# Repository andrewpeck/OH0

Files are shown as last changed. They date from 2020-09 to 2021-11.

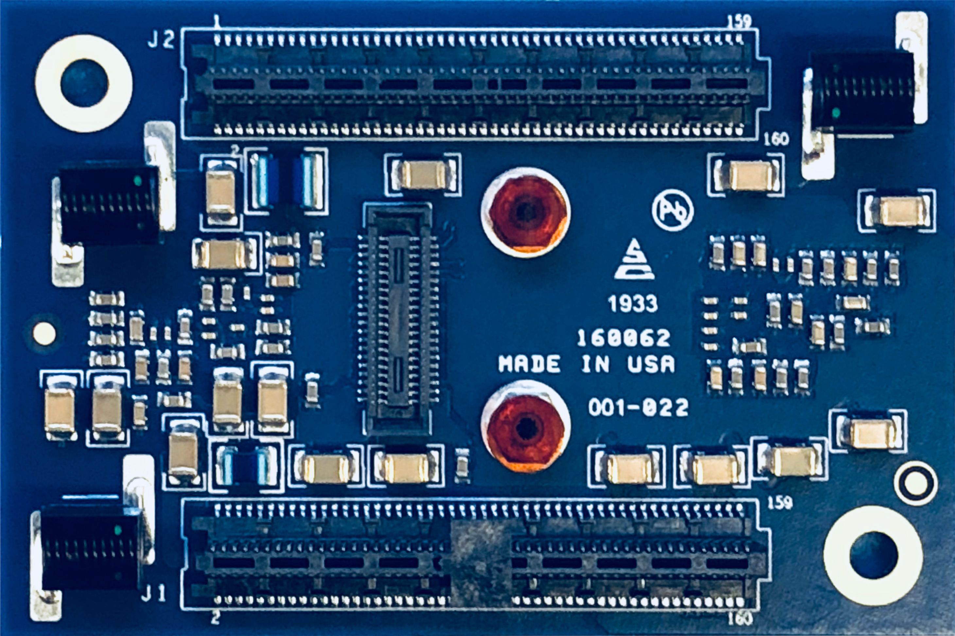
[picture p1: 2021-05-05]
Doc/ASIAGO_BOTTOM.jpeg

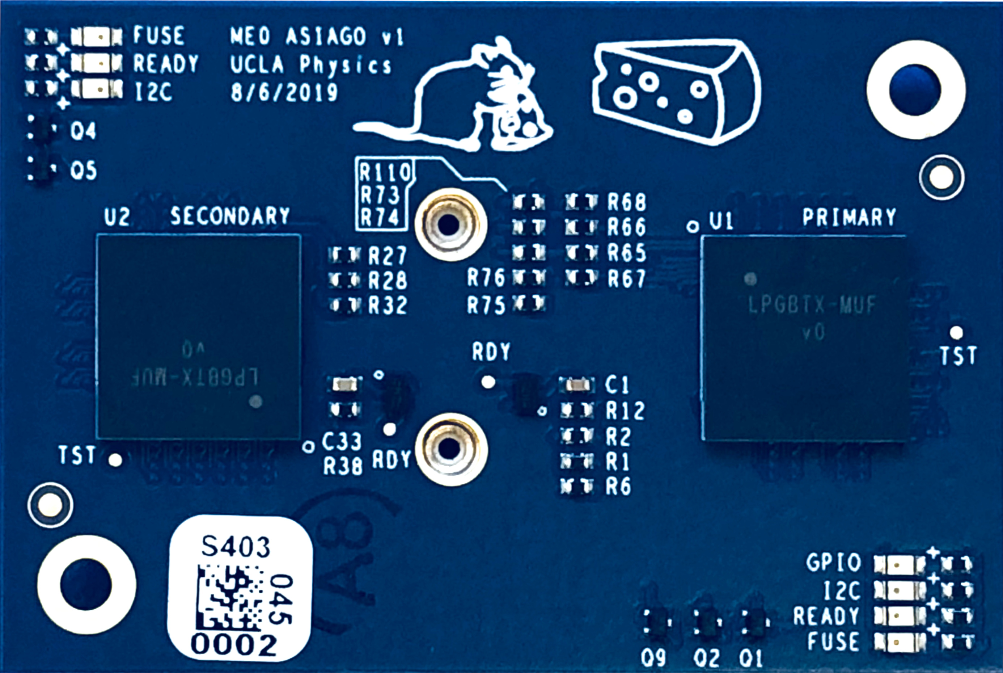
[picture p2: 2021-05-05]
Doc/ASIAGO_TOP.jpeg

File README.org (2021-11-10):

#+TITLE: ME0 ASIAGO

/ASIAGO: a strong-flavored cow's milk cheese originally made in northern Italy. In this case, ASIAGO is the ASIC and Gigabit Optics./

#+html: <p><img width="300" alt="ME0 ASIAGO Top" src="Doc/ASIAGO_TOP.jpeg" /> <img width="300" alt="ME0 ASIAGO Bottom" src="Doc/ASIAGO_BOTTOM.jpeg" /></p>

#+BEGIN_SRC
├── README.org
├── Footprints  ; Allegro Footprints
├── Doc         ; Images, etc.
├── Layout      ; Allegro Layout
├── Padstacks   ; Allegro Padstacks
├── Release     ; Released production files
└── Schematic   ; OrCAD Schematic + Library
#+END_SRC

- [[https://twiki.cern.ch/twiki/pub/CMS/ME0ASIAGO/me0_asiago_interfaces.pdf][ME0 ASIAGO Interfaces]]
- [[https://twiki.cern.ch/twiki/pub/CMS/ME0ASIAGO/ME0_OH_v2_Specification.pdf][ME0 ASIAGO Specifications]]
- [[https://twiki.cern.ch/twiki/bin/view/CMS/ME0ASIAGO][ME0 ASIAGO Twiki]]

* Datasheets
** LPGBT
- [[https://lpgbt.web.cern.ch/lpgbt/manual/][lpGBT Manual]]
- [[https://indico.cern.ch/event/697988/contributions/3075493/attachments/1720215/2776778/lpGBTtutorialTwepp20180921.pdf][lpGBT: A User's Perspective]]
- [[https://espace.cern.ch/GBT-Project/LpGBT/Specifications/LpGbtxSpecifications.pdf][lpGBT Specifications]]
- [[https://espace.cern.ch/GBT-Project/LpGBT/Presentations/Forms/AllItems.aspx][lpGBT Presentations]]
** VTRX+
- [[https://edms.cern.ch/ui/#!master/navigator/project?P:1930058715:1767090345:subDocs][VTRX+ EDMS]]
- [[https://edms.cern.ch/file/1719329/1/VTRxPlus_spec_v2.4.pdf][VTRx+ Specification]]
- [[https://edms.cern.ch/file/2149674/1/VTRxPlusApplicationNote.pdf][VTRx+ Application Note]]
- [[https://www.hirose.com/product/document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][DF40C(2.0)-40DS-0.4V(51)]]
** Other Components
All of these components are meant to be used in non-critical circuitry.
- [[http://rohmfs.rohm.com/en/products/databook/datasheet/discrete/transistor/mosfet/rum001l02t2cl-e.pdf][RUM001L02]]
- [[https://www.ti.com/lit/ds/symlink/sn74aup1g17.pdf][SN74AUP1G17]]
- [[http://suddendocs.samtec.com/catalog_english/st5.pdf][ST5-50-1.50-L-D-P]]
- [[https://www.puiaudio.com/media/SpecSheet/SMT-0340-T-R.pdf][SMT-0340-T-R]]
- [[https://www.diodes.com/assets/Datasheets/BAS521Q.pdf][BAS521Q-13]]
- [[https://optoelectronics.liteon.com/upload/download/DS22-2007-0094/LTST-C193KGKT-5A.PDF][LTST-C193KGKT-5A]] (Green)
- [[https://optoelectronics.liteon.com/upload/download/DS22-2005-077/LTST-C193KRKT-5A.PDF][LTST-C193KRKT-5A]] (Red)
* Misc
**  Design Files:
*** v2
|-----------------------+---------------------------------------------------------------------------------|
| File                  | Link                                                                            |
|-----------------------+---------------------------------------------------------------------------------|
| Schematic PDF         | https://twiki.cern.ch/twiki/pub/CMS/ME0ASIAGO/me0_asiago_schematic_20211110.pdf |
| Artwork PDF           | https://twiki.cern.ch/twiki/pub/CMS/ME0ASIAGO/me0_asiago_artwork_20211110.pdf   |
| Bill of Materials     | https://twiki.cern.ch/twiki/pub/CMS/ME0ASIAGO/me0_asiago_bom_20211110.xlsx      |
| Gerber / Drill / Pick | https://twiki.cern.ch/twiki/pub/CMS/ME0ASIAGO/me0_asiago_artwork_20211110.zip   |
| ODB++                 | https://twiki.cern.ch/twiki/pub/CMS/ME0ASIAGO/me0_asiago_odb_20211110.zip       |
| Orcad/Allegro Project | https://twiki.cern.ch/twiki/pub/CMS/ME0ASIAGO/me0_asiago_project_20211110.zip   |
| 3D Model (step)       | https://twiki.cern.ch/twiki/pub/CMS/ME0ASIAGO/me0_asiago_step_20211110.stp      |
| Stackup               | [[https://twiki.cern.ch/twiki/pub/CMS/ME0ASIAGO/ME0_ASIAGO_-_Rev2_%28Pactron%29--8_%28051421%29.xls][ME0_ASIAGO_Rev2_stackup.xls]]                                                     |
|-----------------------+---------------------------------------------------------------------------------|
*** v1
|-----------------------+---------------------------------------------------------------------------------|
| File                  | Link                                                                            |
|-----------------------+---------------------------------------------------------------------------------|
| Schematic PDF         | https://twiki.cern.ch/twiki/pub/CMS/ME0ASIAGO/me0_asiago_schematic_20190806.pdf |
| Artwork PDF           | https://twiki.cern.ch/twiki/pub/CMS/ME0ASIAGO/me0_asiago_artwork_20190806.pdf   |
| Bill of Materials     | https://twiki.cern.ch/twiki/pub/CMS/ME0ASIAGO/me0_asiago_bom_20190806.xlsx      |
| Gerber / Drill / Pick | https://twiki.cern.ch/twiki/pub/CMS/ME0ASIAGO/me0_asiago_artwork_20190806.zip   |
| ODB++                 | https://twiki.cern.ch/twiki/pub/CMS/ME0ASIAGO/me0_asiago_odb_20190806.zip       |
| Orcad/Allegro Project | https://twiki.cern.ch/twiki/pub/CMS/ME0ASIAGO/me0_asiago_project_20190806.zip   |
| Stackup               | https://twiki.cern.ch/twiki/pub/CMS/ME0ASIAGO/ch1447158_1.pdf                   |
|-----------------------+---------------------------------------------------------------------------------|
** Notes
VL+ Fiber Mapping: #7 = Master RX, # 5 = Master TX, # 6 = Slave RX

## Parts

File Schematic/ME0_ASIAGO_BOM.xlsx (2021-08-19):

Item Number | Quantity | Value | Description | Part Reference | Manufacturer | Manufacturer Part Number
1 | 14 | 4.7 uF | CAP CER 4.7UF 6.3V X5R 0402 | C1 C4 C5 C15 C16 C27 C28 C36 C37 C47 C48 C59 C60 C124 | Murata | GRM155R60J475ME87D
2 | 13 | 47 uF | CAP CER 47UF 10V X5R 0805 | C2 C14 C31 C32 C34 C46 C87 C97 C98 C118 C120 C122 C123 | Murata | GRM21BR61A476ME15L
3 | 23 | 0.47 uF | CAP CER 0.47UF 10V X5R 0402 | C6 C7 C8 C18 C19 C20 C21 C22 C23 C29 C38 C39 C40 C50 C51 C52 C53 C54 C55 C61 C117 C119 C121 | Samsung | CL05A474KP5NNNC
4 | 14 | 10 nF | CAP CER 10000PF 10V X7R 0201 | C10 C11 C12 C13 C24 C25 C30 C42 C43 C44 C45 C56 C57 C62 | Murata | GRM033R71A103KA01D
5 | 8 | Green | LED GREEN CLEAR CHIP SMD | D1 D4 D15 D16 D17 D18 D19 D20 | Lite-On Inc. | LTST-C193KGKT-5A
6 | 2 | Red | LED RED CLEAR CHIP SMD | D9 D10 | Lite-On Inc. | LTST-C193KRKT-5A
7 | 1 | BAS521Q-13 | Diode Standard 300 V 250mA (DC) Surface Mount SOD-523 | D22
8 | 2 | ST5-50-1.50-L-D-P | Samtec Razorbeam 0.5mm Strip Assembly | J1 J2 | Samtec | ST5-50-1.50-L-D-P
9 | 1 | DF40C(2.0)-40DS-0.4V(51) | CONN RCPT 40POS 0.4MM SMD GOLD | J3 | Hirose | DF40C(2.0)-40DS-0.4V(51)
10 | 1 | SMT-0340-T-R |  | LS1
11 | 1 | M2_MOUNT |  | M3
12 | 1 | M2_MOUNT |  | M4
13 | 1 | M1P6_CLEARANCE_HOLE |  | M5
14 | 1 | M1P6_CLEARANCE_HOLE |  | M6
15 | 4 | RUM001L02T2CL | MOSFET N-CH 20V 0.1A VMT3 | Q2 Q5 Q9 Q10 | ROHM | RUM001L02T2CL
16 | 10 | 4.7k | RES SMD 4.7K OHM 5% 1/10W 0402 | R1 R2 R27 R28 R73 R74 R75 R76 R86 R122 | Panasonic | ERJ-2GEJ472X
17 | 5 | 270R | RES SMD 270 OHM 5% 1/10W 0402 | R3 R29 R83 R84 R109 | Panasonic | ERJ-2GEJ271X
18 | 3 | 1k | RES SMD 1K OHM 0.1% 1/16W 0402 | R66 R111 R112 | Panasonic | ERA-2AEB102X
19 | 1 | 500R |  | R68 | Panasonic
20 | 1 | 4.7k |  | R110
21 | 3 | 0R | RES SMD 0 OHM 1% 1/10W 0402 | R113 R114 R130 | Panasonic | RMCF0402ZT0R00
22 | 1 | 1M |  | R116
23 | 2 | 470k |  | R117 R137
24 | 7 | 1k |  | R118 R131 R132 R133 R134 R135 R138
25 | 2 | 999G | Do Not Stuff | R119 R129 |  | Do Not Place
26 | 2 | 1R |  | R120 R121 |  | RC0402FR-071RL
27 | 1 | 33R |  | R136
28 | 1 | NTCG103UH103JT1 |  | RT1 |  | NTCG103UH103JT1
29 | 3 | TPPAD | Do Not Stuff | TP7 TP20 TP21 | Do Not Stuff | Do Not Stuff
30 | 2 | LpGBT | CERN LpGBT | U1 U2 | CERN | LpGBT
31 | 1 | SN74AUP1G17DRY | IC BUFFER NON-INVERT 3.6V 6SON | U3 | Texas Instruments | SN74AUP1G17DRYR

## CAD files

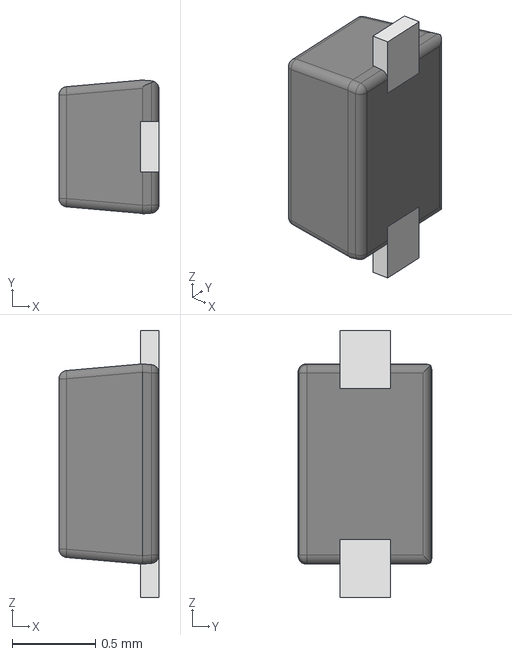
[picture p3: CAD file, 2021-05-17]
Footprints/STEP/SOD523.stp
0.6 x 0.803 x 1.60 mm
SOD523 LF
SOD523 compound

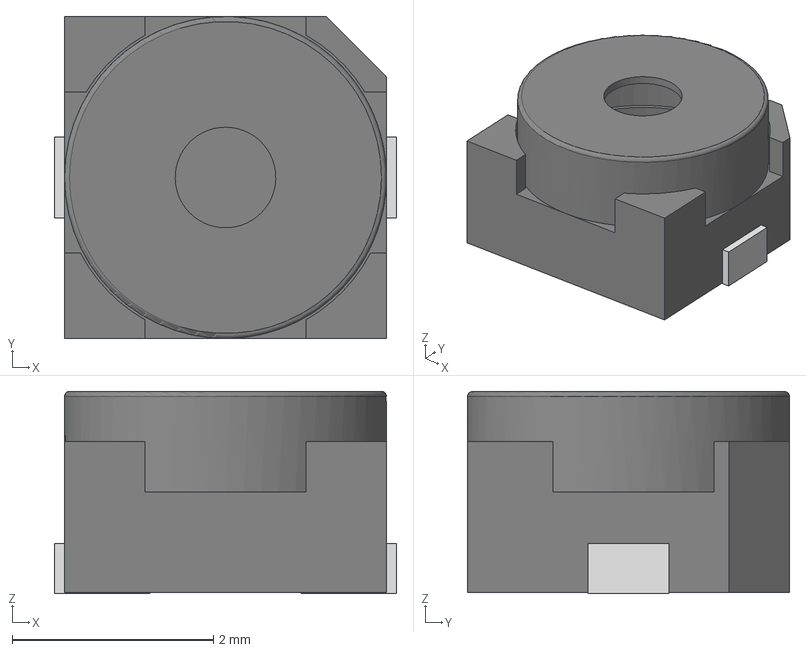
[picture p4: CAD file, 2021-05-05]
Footprints/STEP/SMT-0340-T-R.stp
3.40 x 3.20 x 2.01 mm
Lower Housing
Upper Housing

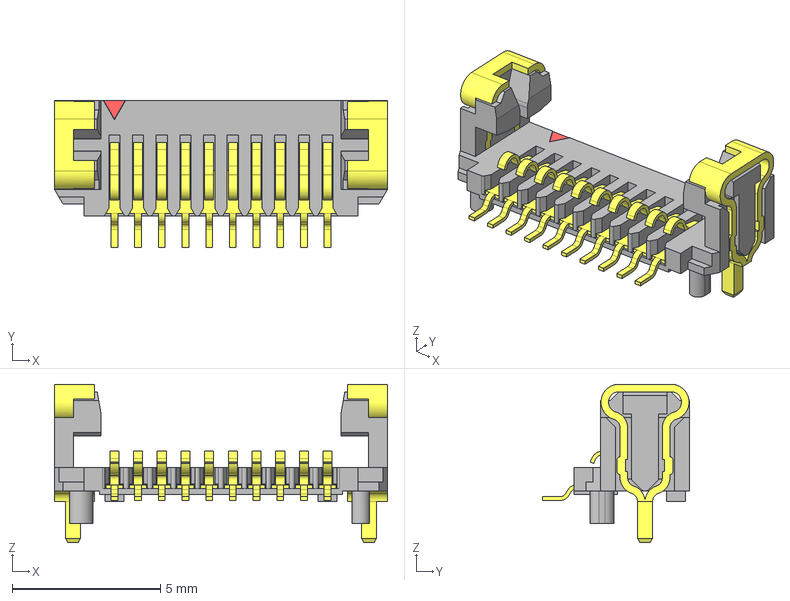
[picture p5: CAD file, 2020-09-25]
Footprints/STEP/UCC8-010-1-H-S-1-A.stp
11.2 x 4.96 x 5.35 mm
_UCC8-010-1-H-S-1-A_t
_UCC8-010-1-H-S-1-A_wt x 2
_UCC8-010-1-H-S-1-A_p
_UCC8-010-1-H-S-1-A_tr

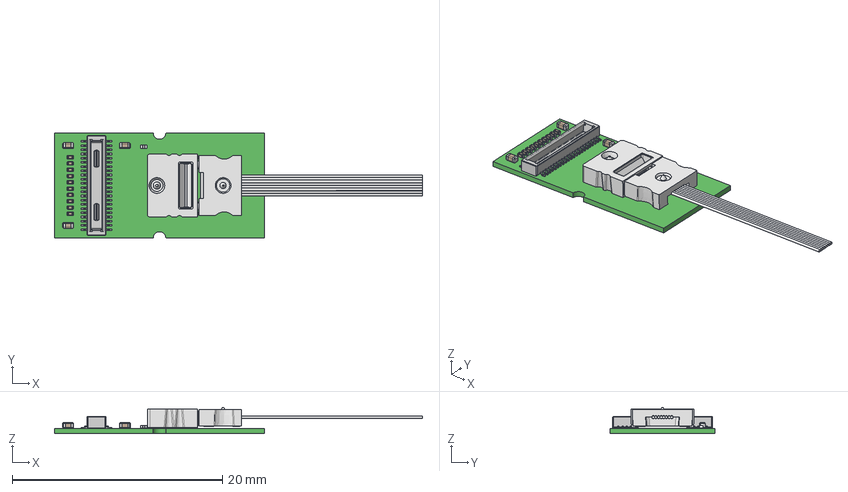
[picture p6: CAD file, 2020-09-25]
Footprints/STEP/CERN_VTRxPlus_V7_with_pigtail.stp
35.0 x 10.0 x 2.51 mm
Board
CAPC0603X33N x 10
RESC0603X28N
DF40C-40DP
PHILIPS_ULMPIN-14-TT-N0101U
PHILIPS_ULM850-14-TT-N0104U
CAPC1005X55N x 3
CERN_GBTIA
CERN_LDQ10v2
OT-006_f
OT-007_f
ribbon

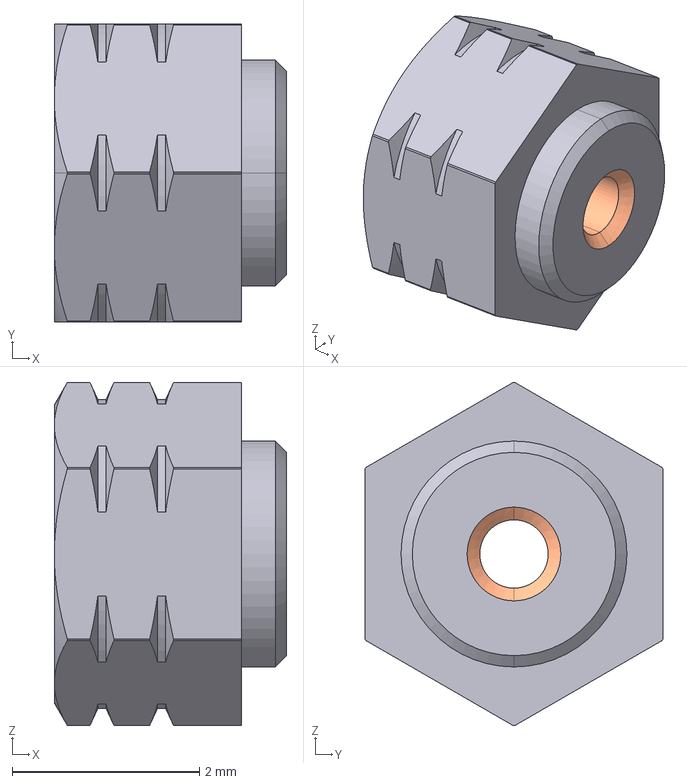
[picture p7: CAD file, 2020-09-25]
Footprints/STEP/SMTSO-M1-2ET-PennEngineering-05-24-2018.stp
2.48 x 3.18 x 3.66 mm

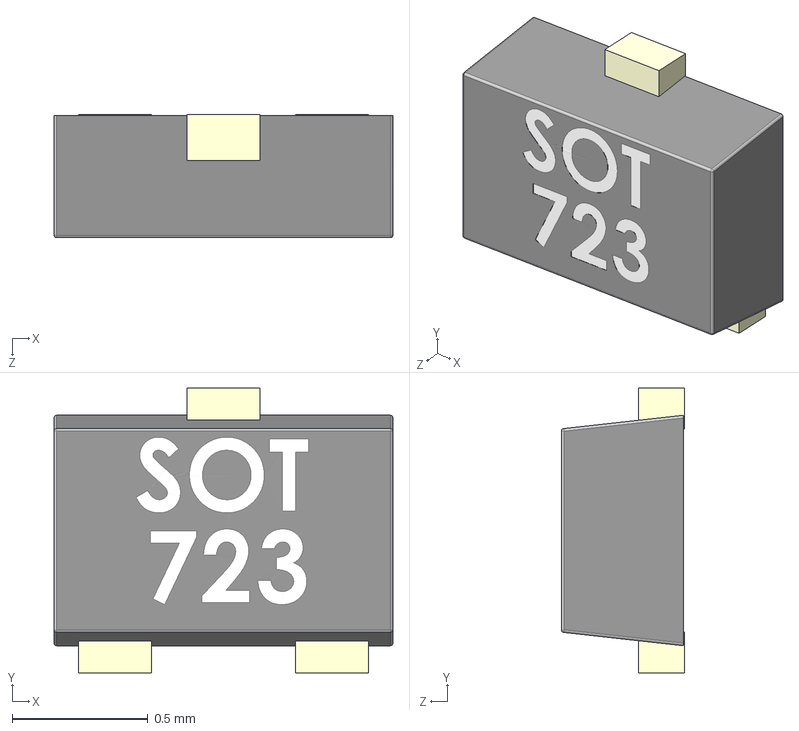
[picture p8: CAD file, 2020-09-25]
Footprints/STEP/User Library-SOT-723.step
1.25 x 1.05 x 0.455 mm

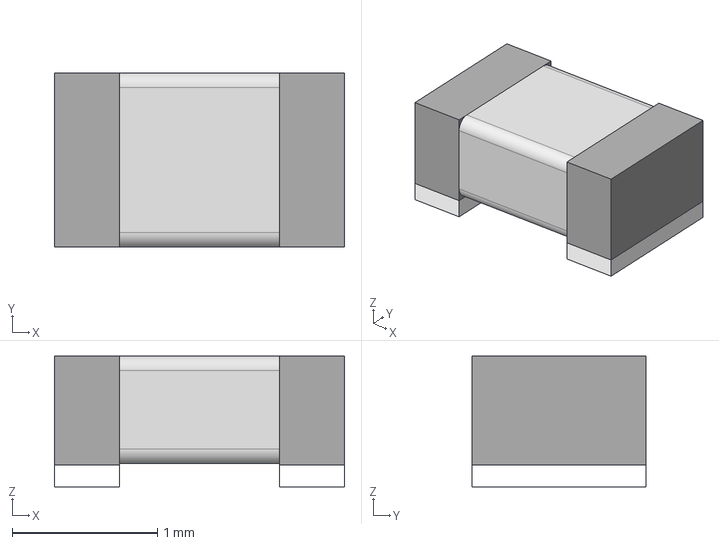
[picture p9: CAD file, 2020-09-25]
Footprints/STEP/LQW21HN.stp
2.00 x 1.20 x 0.9 mm

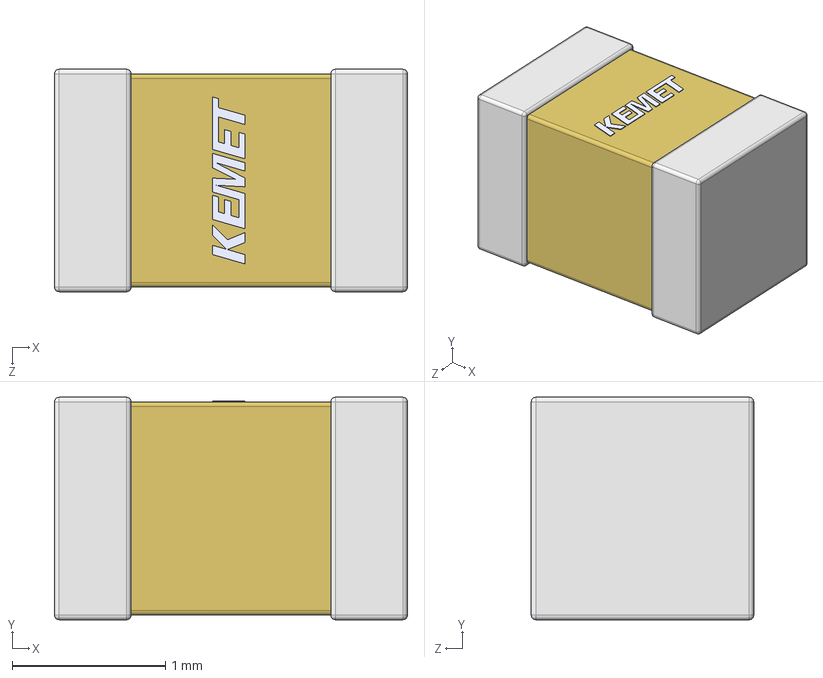
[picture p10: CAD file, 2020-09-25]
Footprints/STEP/C0805.step
2.30 x 1.45 x 1.45 mm

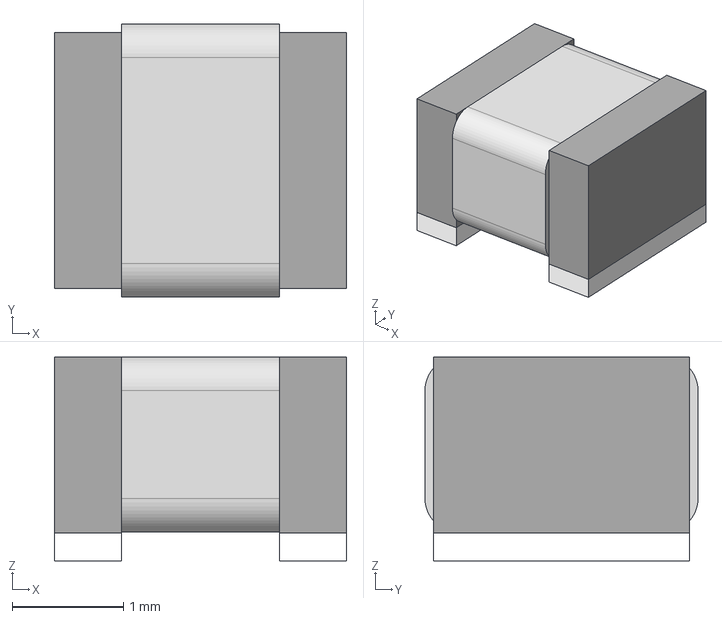
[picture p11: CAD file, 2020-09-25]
Footprints/STEP/LQW2UAN.stp
2.62 x 2.45 x 1.83 mm

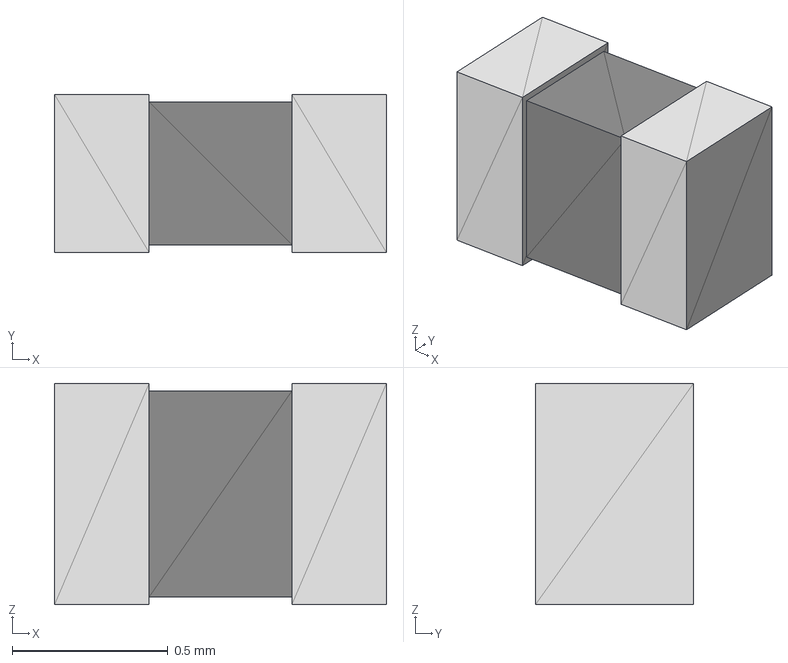
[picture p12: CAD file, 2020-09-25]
Footprints/STEP/RES_0402.stp
1.07 x 0.508 x 0.711 mm

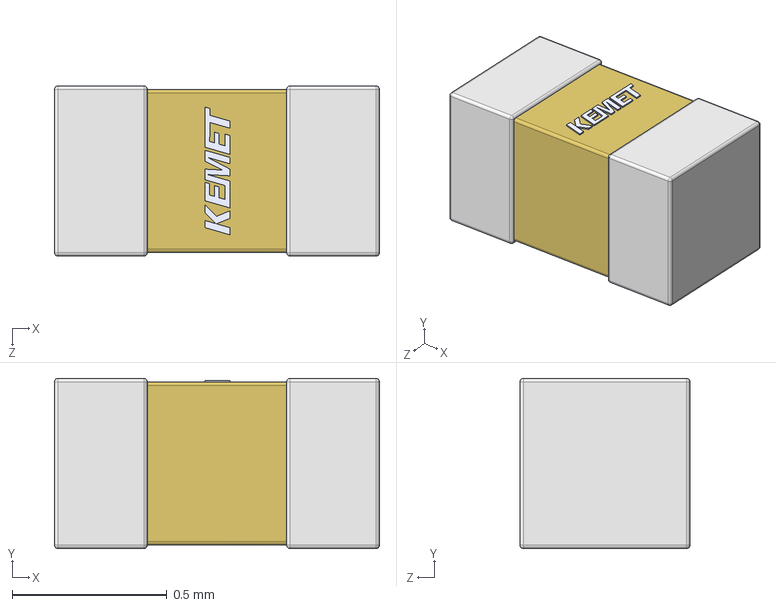
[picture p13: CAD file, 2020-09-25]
Footprints/STEP/C0402.step
1.05 x 0.55 x 0.55 mm

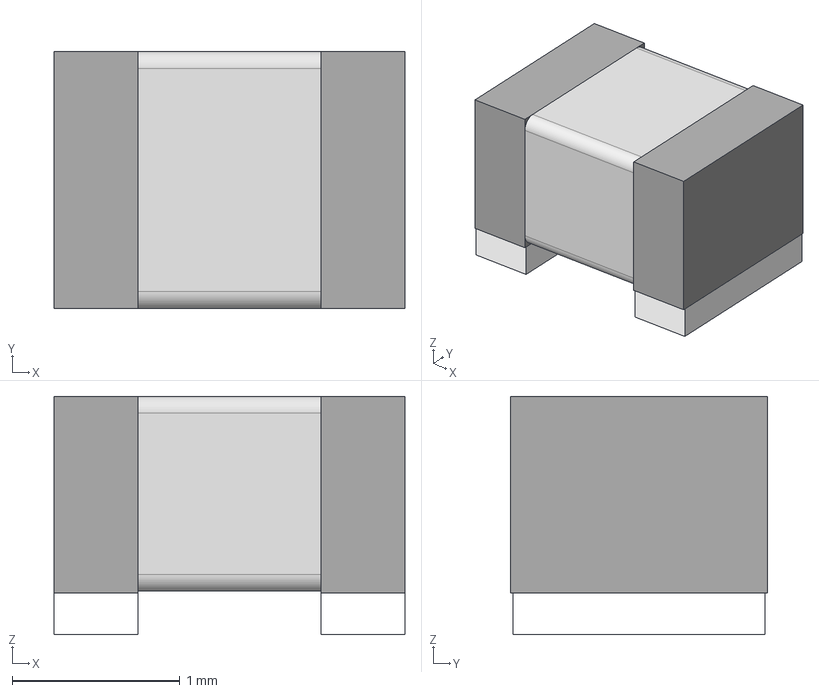
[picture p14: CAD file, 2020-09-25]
Footprints/STEP/LQW2BAN.stp
2.09 x 1.53 x 1.42 mm

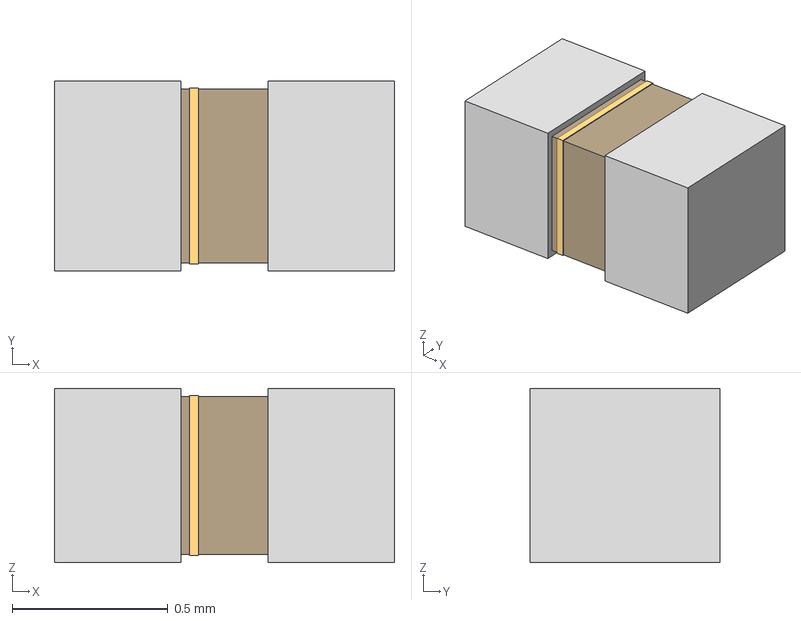
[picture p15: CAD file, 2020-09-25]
Footprints/STEP/CAP_0402C.step
1.09 x 0.61 x 0.559 mm

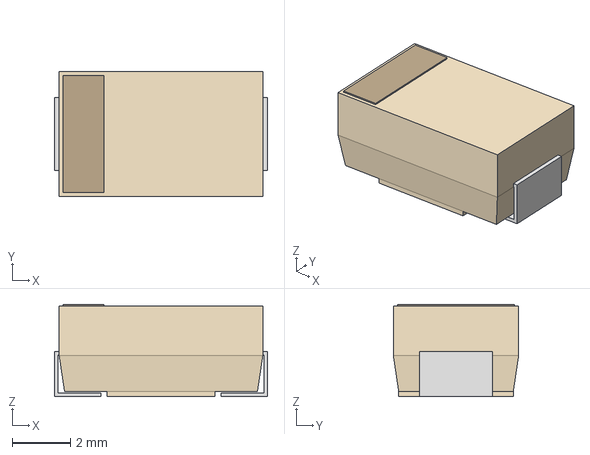
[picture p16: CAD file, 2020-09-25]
Footprints/STEP/PCAP7343-31_Kemet-M.step
7.29 x 4.29 x 3.15 mm

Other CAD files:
Footprints/STEP/LQW31HN.stp
Footprints/STEP/LQW2BHN.stp
Footprints/STEP/CAP_0402C-L.step
Footprints/STEP/C1206.step
Footprints/1812sms-r15_l_.psm
Footprints/1812sms0r15_l_.psm
Footprints/6-ufdfn.psm
Footprints/STEP/90910A310_SCREW.STEP
Footprints/STEP/AIAC-4125C.STEP
Footprints/STEP/C0201.step
Footprints/STEP/CAP_0402C-M.step
Footprints/STEP/Coilcraft-1812SMS-R15.STEP
Footprints/STEP/DF40C-2P0-40DS.stp
Footprints/STEP/DF40C-40DP.stp
Footprints/STEP/DF40GB-48DP-0.4V.stp
Footprints/STEP/DRY0006A.stp
Footprints/STEP/LED0603.step
Footprints/STEP/SMTSO-080-2ET-PennEngineering-05-17-2018.stp
Footprints/STEP/SRP2010 series.stp
Footprints/STEP/UDFN8_1P45X1.step
Footprints/aiac-4125c.psm
Footprints/c0201.psm
Footprints/c0402.psm
Footprints/c0603.psm
Footprints/c0805.psm
Footprints/c1206.psm
Footprints/cap_0402c-m.psm
Footprints/cap_0402c.psm
Footprints/coilcraft_1812sms0r15_l_.psm
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

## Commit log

2019-04-02 Updates 20190401
    [1812sms-r15_l_.psm, 1812sms0r15_l_.psm, 6-ufdfn.psm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]
2019-05-22 updates 05212019
    [1812sms-r15_l_.psm, AIAC-4125C.STEP, Coilcraft-1812SMS-R15.STEP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]
2019-06-14 Release 20190613
    [OH0.DSN]
2019-07-24 Mirror lpGBT package; start updated layout
    [OH0.DSN, lpgbt_wiz.psm, m2_mount.psm]
2019-07-31 Additional pinswapping; all non-power signals routed
    [OH0.DSN]
2019-08-03 Updates from today; fully routed with no DRC
    [OH0.DSN]
2019-08-06 Misc. cleanup + rerouting
    [OH0.DSN]
2020-09-25 WIP updates
    [90910A310_SCREW.STEP, AIAC-4125C.STEP, C0402.step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]
2020-09-25 Schematic updates
    [OH0.DSN]
2020-11-02 Correct I2C pin number bug
    [OH0.DSN]
2020-11-02 Update title block
    [OH0.DSN]
2020-11-02 Reannotate schematic
    [OH0.DSN]
2020-11-02 Update netlist
    [OH0.DSN]
2020-11-04 Update LPGBT symbol (from Joseph)
    [OH0.DSN]
2020-11-05 Remove extra 2.5V resistor
    [OH0.DSN]
2020-11-05 Remove CFG_SEL LED
    [OH0.DSN]
2020-11-05 Change VTRX reset gpio assignment
    [OH0.DSN]
2020-11-05 Remove unnecessary CFG_SEL resistor
    [OH0.DSN]
2021-04-20 Incorporate suggestions from abhisek
    [OH0.DSN]
2021-04-20 Schematic cleanup; remove CONFIG_SEL
    [OH0.DSN]
2021-04-21 Continue layout, minor schematic changes
    [OH0.DSN, vl_plus.psm]
2021-05-05 Update mounting hole drawing
    [m1p6_clearance_hole.psm]
2021-05-05 Layout updates
    [OH0.DSN]
2021-05-05 100% routed; 101 drcs
    [OH0.DSN, smt-0340.psm, sod523.psm]
2021-05-17 Update footprint silkscreen
    [smt-0340.psm]
2021-05-17 First draft of v2
    [OH0.DSN, SOD523.stp]
2021-07-16 2021/07/16
    Release for review
    [ME0_ASIAGO_BOM.xlsx, OH0.DSN]
2021-08-19 RESETB updates
    - Change LPGBT RESETB pullup from 4.7k to 1.0k
    - Add 1.0k pullup to the GPIO output which connects to the servant
    RESETB input
    [ME0_ASIAGO_BOM.xlsx, OH0.DSN]
2021-08-19 Update layout w/ additional resistor; add corner cutout
2021-08-26 2021/08/26
    - From stephen's feedback:
    - Tie unused ADC inputs to ground
    - Cleanup some routing
    - Fix some silkscreen issues
    [OH0.DSN]
2021-11-10 2021/11/10: update silkscreen
